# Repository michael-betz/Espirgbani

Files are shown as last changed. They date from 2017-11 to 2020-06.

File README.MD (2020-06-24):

# ESP Pinball RGB Animation clock

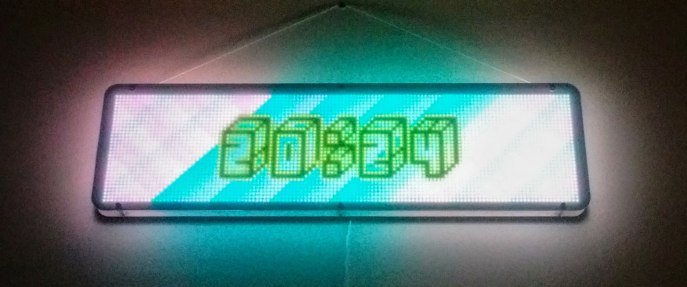
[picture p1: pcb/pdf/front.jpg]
clock


A LED-matrix clock, based on ESP32 and sprite_tm's I2S DMA driver.

__Note:__ 
the firmware here is outdated and will be removed in the future. 

[Espirgbani_pio](https://github.com/yetifrisstlama/espirgbani_pio) is up to date, has more features, less bugs, higher frame-rate and is much easier to build.

[Project log](http://yetifrisstlama.blogspot.com/2018/02/the-esp32-pinball-rgb-matrix-animation.html).

# PCB
Fits inside one of the 64x32 panels.

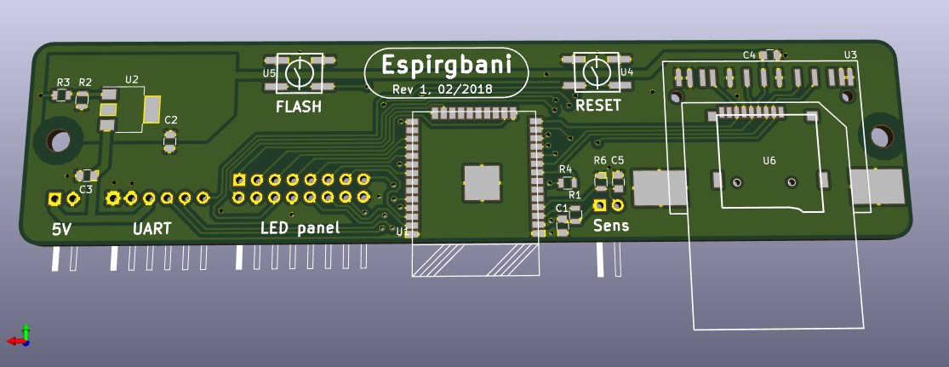
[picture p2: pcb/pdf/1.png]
back


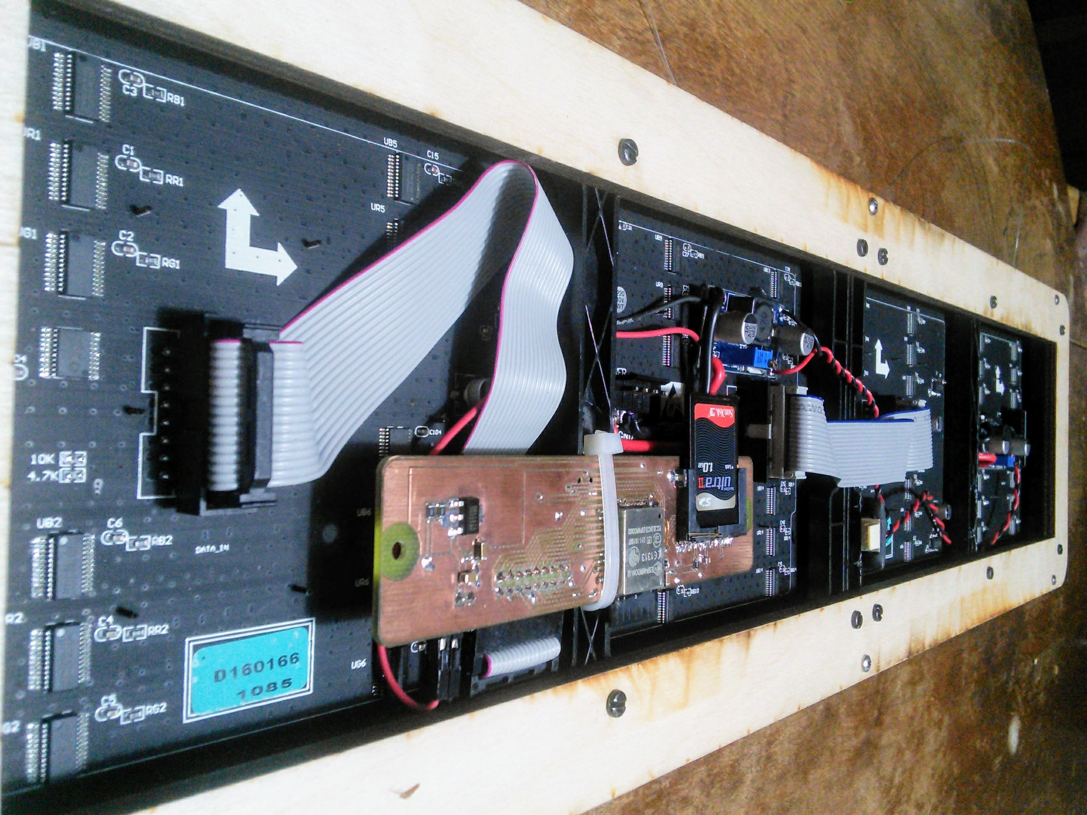
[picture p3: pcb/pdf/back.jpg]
wiring


### Revisions
Changes included in Rev 1
  * Change programming port from custom pogo-pins to a normal header
  * Add input for ambient light level sensor
  * Re-arrange the mounting holes
  * Add second footprint for a uSD card

# Building
Unfortunately the projects which I based this software on are either completely obsolete or they moved on a lot. Building still works (as of April 2020) but only when using exactly the versions and git commits as specified below.

install [version 5.2.0 of `xtensa-esp32-elf` toolchain](https://dl.espressif.com/dl/xtensa-esp32-elf-linux64-1.22.0-80-g6c4433a-5.2.0.tar.gz) and put it in your `PATH`.

```bash
$ xtensa-esp32-elf-gcc --version
xtensa-esp32-elf-gcc (crosstool-NG crosstool-ng-1.22.0-80-g6c4433a) 5.2.0
Copyright (C) 2015 Free Software Foundation, Inc.
This is free software; see the source for copying conditions.  There is NO
warranty; not even for MERCHANTABILITY or FITNESS FOR A PARTICULAR PURPOSE.
```

install the esp-idf library.
```bash
git clone https://github.com/espressif/esp-idf.git
cd esp-idf
git checkout b173cf28174b17f7df96c298f83c16a00d22e312
git submodule init
git submodule update
cd components
git clone --recurse-submodules git@github.com:yetifrisstlama/libesphttpd.git
export IDF_PATH=<insert_path>/esp-idf
```

Clone Espirgbani, build and flash it ...

```bash
git clone git@github.com:yetifrisstlama/Espirgbani.git
cd Espirgbani/src
make
make flash     # program esp32 over serial port, hold the FLASH button!
make web-flash # program esp32 over wifi, set hostname in Makefile
```

## fast-seek
For a smoother animation playback, the fast-seek option needs to be enabled in
the fatfs library. Use the provided .patch file ...
```bash
cd esp-idf
patch -p1 -i ../Espirgbani/src/0001-Enable-FASTSEEK-option-in-FatFs.patch
```

# SD card instructions
Format as FAT32, then copy the following files:
  * `./settings.json`
  * `./runDmd.img`
  * `./fnt/{d}.fnt`
  * `./fnt/{d}_0.bmp`

## example `settings.json`
```json
{
    "panel": {
        "test_pattern": false,
        "tp_brightness":  10,
        "is_clk_inverted": true,
        "column_swap": false,
        "latch_offset": 0,
        "extra_blank": 1,
        "clkm_div_num": 4
    },
    "power": {
        "hi": {
            "h": 9,
            "m": 0,
            "p": 50,
            "pingIp": "192.168.1.208"
        },
        "lo": {
            "h": 22,
            "m": 45,
            "p": 1
        }
    },
    "delays": {
        "font":  60,
        "color": 10,
        "ani":   15,
        "ping":  60
    },
    "log_level": "W",
    "timezone": "PST8PDT,M3.2.0,M11.1.0",
    "hostname": "espirgbani",
    "wifis": {
        "<wifi-ssid>": {
            "pw": "<wifi-password>"
        }
    }
}
```
### `panel` section
Not all LED panels are the same. Here the timing parameters of the I2S panel driver can be configured.

  * `test_pattern`: if true, enters a LED panel test mode instead of normal operation
  * `tp_brightness`: brightness of the test pattern, from 1 to 127. Current draw gets ridiculous for the higher values
  * `is_clk_inverted`: if `false`, data changes on the rising clock edge. If `true`, data is stable on the rising clock edge (most panels need `true`)
  * `column_swap`: if true, swap each pair of vertical columns
  * when `latch_offset = 0`: latch row-data with last pixel. For positive / negative numbers the latching happens n clock cycles earlier / later. Shifts the image horizontally
  * `extra_blank` adds N additional delay cycles after latching before enabling the LEDs to prevent ghosting artifacts from one row to another
  * `clkm_div_num` sets the I2S clock divider from 1 to 128. Set it too high and get flicker,  too low get ghost pixels. `4` (= 8 MHz pixel clock) is a good compromise for my panels

### `power` section
controls the display brightness depending on current time.

  * Switches to brightness `90` at `9:00`
  * But only if `192.168.1.208` responds to pings
  * Switches to brightness `1` at `22:45`

### `delays` section
controls delays between random animations, color and font changes.

  * Changes the clock font every 60 minutes
  * Changes color of the clock font every 10 minutes
  * Plays a new pinball animation every 15 seconds
  * tries to ping `pingIp` every 60 seconds

### `log_level`
is the logging level for the serial port and the web-console on startup. Can be one of the following letters: `E = ERROR`, `W = WARN`, `I = INFO`, `D = DEBUG`, `V = VERBOSE`

### `timezone`
is the local timezone in [TZ format](https://www.gnu.org/software/libc/manual/html_node/TZ-Variable.html). Look it up [here](https://github.com/nayarsystems/posix_tz_db/blob/master/zones.csv).

Note that once running and connected to the wifi, the settings.json file can be edited through the web interface.

## how to get `runDmd.img`
  * Find a run-dmd image file and write it to SD card according to their instructions (HDD Raw Copy Tool and Windows required)
  * In linux, dump the first few hundred megabytes of the SD card to a file:
  ```bash
  sudo dd if=/dev/sdb of=./runDmd.img bs=1M count=125
  ```

## how to get the font `.bmp` and `.fnt` files
  * Find some nice fonts which look good at small size and copy the `.ttf` files into the git tree at `./dev/fonts`
  * Use [bmFont](http://www.angelcode.com/products/bmfont/) (works well with wine in linux) to generate the bitmap fonts. Good settings are provided in `dev/clockFont.bmfc`
    * Width: 52, Height: 2000
    * 32 bit per pixel (A = one, R = glyph, G = outline, B = zero)
    * .png texture file
    * binary .fnt descriptor file
    * Size: 30 px, Outline thickness: 1 px
  * Use imagemagick to convert all image files to bmp format
  * Rename them to 0_0.bmp, 0.fnt;  1_0.bmp, 1.fnt, ...
  * Alternatively, run `./dev/generateFonts.sh` which should automate these steps

## Pre-built binaries (TLDR!)
Prebuilt firmware binaries for the ESP32 and the files for the (FAT32) SD card are [here](https://github.com/yetifrisstlama/Espirgbani/releases/tag/v1.0).

# TODO
  * rewrite .json settings

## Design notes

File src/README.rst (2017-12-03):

EXAMPLE TO USE I2S TO DRIVE A LED DISPLAY
=========================================

This is example code to drive one of the common 64x32-pixel RGB LED
screen. It illustrates the parallel output mode of the I2S peripheral.

See main/app_main.c for more information and how to hook up a display.

This is PRELIMINARY CODE and Espressif gives no support on it.

https://esp32.com/viewtopic.php?f=17&t=3188&sid=14a745f714c2d902012ac641bb31025d

Modified to 128x64 and with GLCD / webserver code by M. Betz

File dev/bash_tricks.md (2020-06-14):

# extract all zip files
```bash
for f in *zip; do unar $f; done
```

# move all .ttf files into ./fnt
```bash
shopt -s globstar
for f in **/*.ttf; do mv "$f" ./fnt; done
```

# rename to 00.ttf, 01.ttf, etc
```bash
i=0; for f in *.ttf; do mv "$f" "$(printf %02d.ttf $i)"; i=$((i+1)); done
```

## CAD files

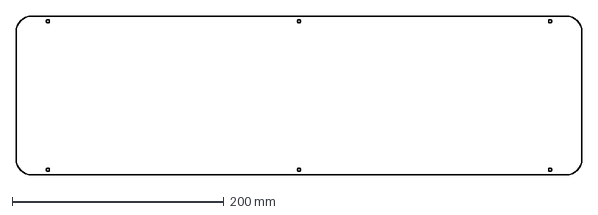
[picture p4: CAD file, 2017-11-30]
pcb/lasercut/frontAcryl.dxf
534.0 x 150.0 mm

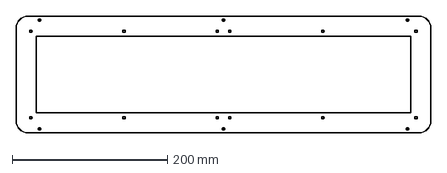
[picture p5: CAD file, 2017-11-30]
pcb/lasercut/backWood.dxf
534.0 x 150.0 mm

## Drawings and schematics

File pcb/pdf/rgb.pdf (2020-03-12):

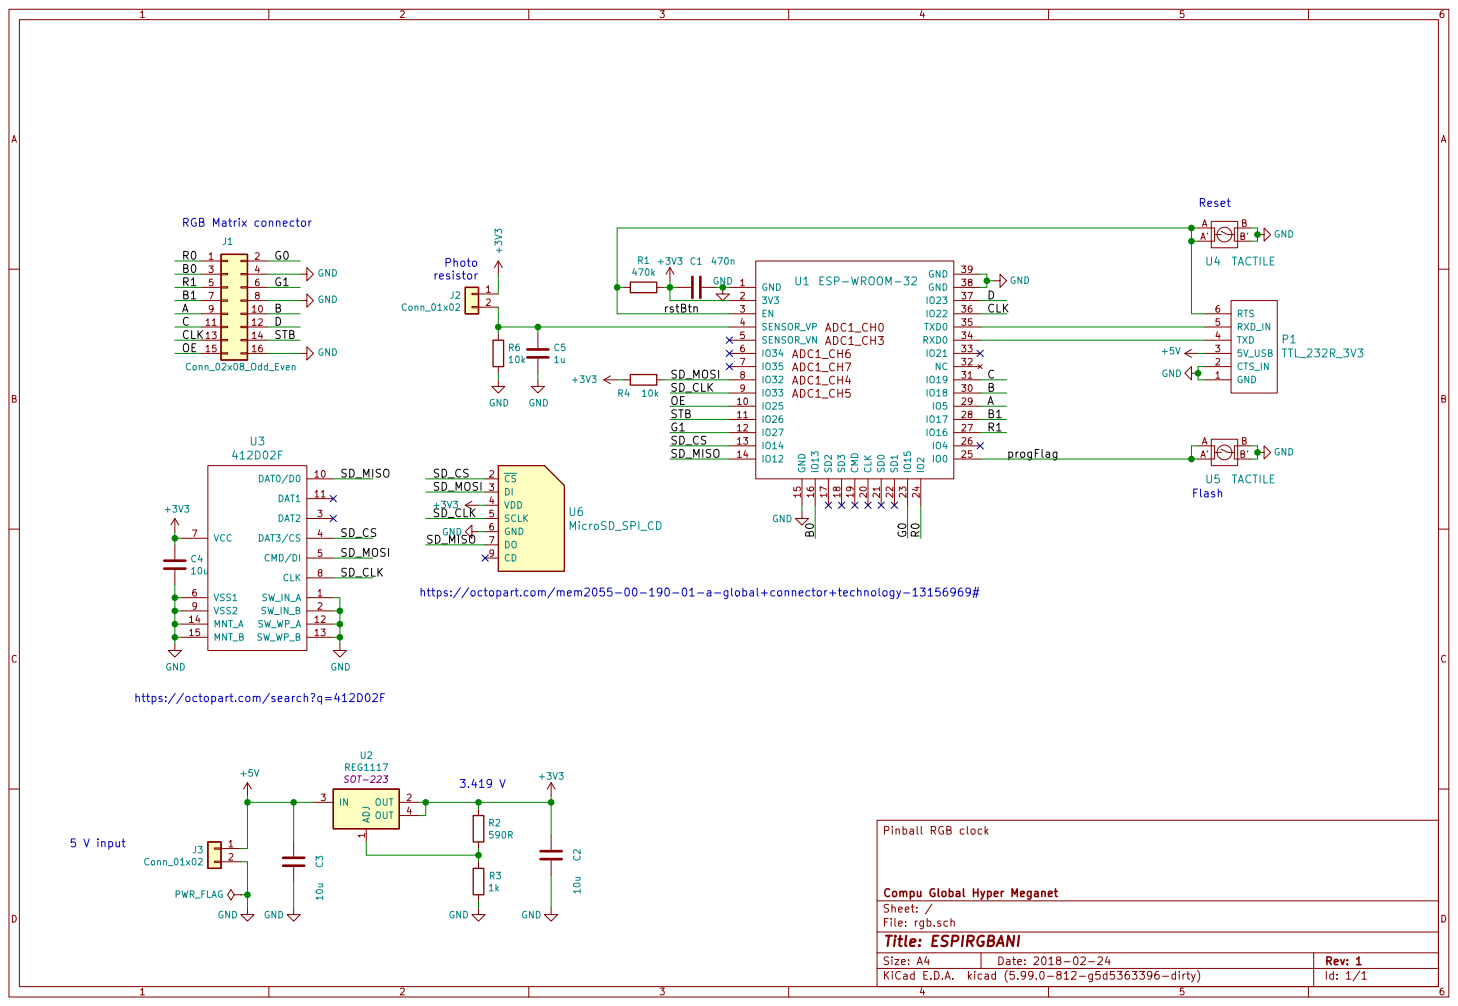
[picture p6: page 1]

https://octopart.com/mem2055-00-190-01-a-global+connector+technology-13156969# Photo

https://octopart.com/search?q=412D02F

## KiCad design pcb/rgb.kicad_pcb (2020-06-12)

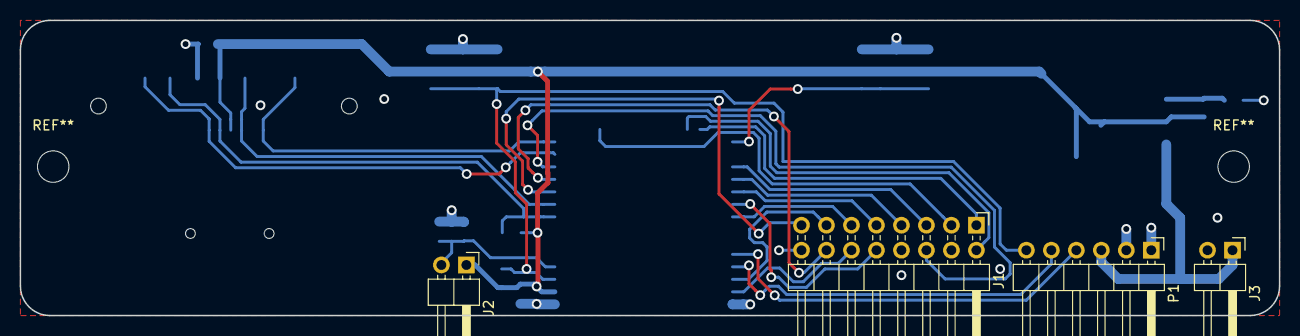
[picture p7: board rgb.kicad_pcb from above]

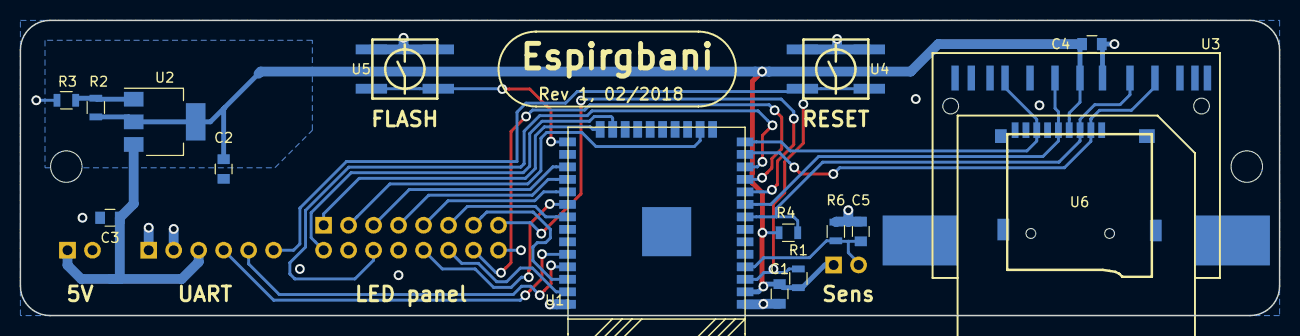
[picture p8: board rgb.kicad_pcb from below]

Board: 2 copper layers, 128.0 x 30.0 mm, 20 parts (16 on the bottom side), 26 nets.

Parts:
C1: 470n; C_0805
C2, C3, C4: 10u; C_0805
C5: 1u; C_0805
J1: Conn_02x08_Odd_Even; Pin_Header_Angled_2x08_Pitch2.54mm
J2, J3: Conn_01x02; Pin_Header_Angled_1x02_Pitch2.54mm
P1: TTL_232R_3V3; Pin_Header_Angled_1x06_Pitch2.54mm
R1: 470k; R_0805
R2: 590R; R_0805
R3: 1k; R_0805
R4, R6: 10k; R_0805
U1: ESP-WROOM-32
U2: REG1117; SOT-223
U3: 412D02F; RPIA_SD_CARD
U4, U5: TACTILE; EVQQ2
U6: MicroSD_SPI_CD; GCT-MEM2055-00-190-01-A

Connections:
+3V3: C1.2, C2.2, C4.1, J2.1, R1.1, R2.1, R4.2, U1.2, U2.2, U2.4, U3.7, U6.4
+5V: C3.2, J3.1, P1.3, U2.3
/A: J1.9, U1.29
/B: J1.10, U1.30
/B0: J1.3, U1.16
/B1: J1.7, U1.28
/C: J1.11, U1.31
/CLK: J1.13, U1.36
/D: J1.12, U1.37
/G0: J1.2, U1.23
/G1: J1.6, U1.12
/OE: J1.15, U1.10
/R0: J1.1, U1.24
/R1: J1.5, U1.27
/SD_CLK: U1.9, U3.8, U6.5
/SD_CS: U1.13, U3.4, U6.2
/SD_MISO: U1.14, U3.10, U6.7
/SD_MOSI: R4.1, U1.8, U3.5, U6.3
/STB: J1.14, U1.11
/progFlag: U1.25, U5.A, U5.A'
/rstBtn: P1.6, R1.2, U1.3, U4.A, U4.A'
GND: C1.1, C2.1, C3.1, C4.2, C5.2, J1.4, J1.8, J1.16, J3.2, P1.1, P1.2, R3.2, R6.2, U1.1, U1.15, U1.38, U1.39, U3.1, U3.2, U3.6, U3.9, U3.12, U3.13, U3.14, U3.15, U4.B, U4.B', U5.B, U5.B', U6.6
unnamed: C5.1, J2.2, R6.1, U1.4
unnamed: P1.4, U1.34
unnamed: P1.5, U1.35
unnamed: R2.2, R3.1, U2.1

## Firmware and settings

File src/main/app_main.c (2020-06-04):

// Copyright 2017 Espressif Systems (Shanghai) PTE LTD
//
// Licensed under the Apache License, Version 2.0 (the "License");
// you may not use this file except in compliance with the License.
// You may obtain a copy of the License at
//
//     http://www.apache.org/licenses/LICENSE-2.0
//
// Unless required by applicable law or agreed to in writing, software
// distributed under the License is distributed on an "AS IS" BASIS,
// WITHOUT WARRANTIES OR CONDITIONS OF ANY KIND, either express or implied.
// See the License for the specific language governing permissions and
// limitations under the License.

#include <string.h>
#include <stdio.h>
#include <stdlib.h>
#include <math.h>
#include <time.h>
#include "driver/gpio.h"
#include "esp_log.h"
#include "wifi_startup.h"
#include "web_console.h"
#include "rgb_led_panel.h"
#include "sdcard.h"
#include "animations.h"
#include "frame_buffer.h"
#include "bmp.h"
#include "font.h"
#include "shaders.h"
#include "fast_hsv2rgb.h"
#include "app_main.h"
#include "json_settings.h"

static const char *T = "MAIN_APP";

int g_maxFnt = 0;
int g_fontNumberRequest = 0;

void seekToFrame(FILE *f, int byteOffset, int frameOffset) {
    byteOffset += DISPLAY_WIDTH * DISPLAY_HEIGHT * frameOffset / 2;
    fseek(f, byteOffset, SEEK_SET);
}

void playAni(FILE *f, headerEntry_t *h) {
    uint8_t r,g,b;
    fast_hsv2rgb_32bit(RAND_AB(0,HSV_HUE_MAX), HSV_SAT_MAX, HSV_VAL_MAX, &r, &g, &b);
    for(int i=0; i<h->nFrameEntries; i++) {
        frameHeaderEntry_t fh = h->frameHeader[i];
        if(fh.frameId == 0) {
            startDrawing(2);
            setAll(2, 0xFF000000);
        } else {
            seekToFrame(f, h->byteOffset+HEADER_SIZE, fh.frameId-1);
            startDrawing(2);
            setFromFile(f, 2, SRGBA(r,g,b,0xFF));
        }
        doneDrawing(2);
        // updateFrame();
        vTaskDelay(fh.frameDur / portTICK_PERIOD_MS);
    }
}

void manageBrightness(struct tm *timeinfo) {
    static int nBadPings = 0;
    cJSON *jPow = jGet(getSettings(), "power");
    cJSON *jDel = jGet(getSettings(), "delays");
    cJSON *jHi  = jGet(jPow, "hi");
    cJSON *jLo  = jGet(jPow, "lo");
    const char *pingIpStr;
    uint32_t pingRespTime;
    ip4_addr_t ip;
    pingIpStr = jGetS(jHi, "pingIp", "0.0.0.0");
    ip4addr_aton(pingIpStr, &ip);
    int maxBadPings = jGetI(jDel, "ping", 1);
    if (maxBadPings <= 0) maxBadPings = 1;
    int iHi = jGetI(jHi, "m", 0) + jGetI(jHi, "h", 9) * 60;
    int iLo = jGetI(jLo, "m", 45) + jGetI(jLo,"h", 22) * 60;
    int iCur = timeinfo->tm_min + timeinfo->tm_hour * 60;
    if (iCur >= iHi && iCur < iLo) {
        // Daylite mode
        brightNessState = BR_DAY;
        if (ip.addr > 0 && ip.addr < 0xFFFFFFFF) {
            if ((pingRespTime = isPingOk(&ip, 3000))) {
                nBadPings = 0;
                ESP_LOGD(T,"Ping response from %s in %d ms", ip4addr_ntoa(&ip), pingRespTime);
            } else {
                nBadPings++;
                ESP_LOGW(T,"Ping timeout %d on %s", nBadPings, ip4addr_ntoa(&ip));
            }
            if (nBadPings >= maxBadPings) {
                g_rgbLedBrightness = jGetI(jLo, "p", 1);
            } else {
                g_rgbLedBrightness = jGetI(jHi, "p", 20);
            }
        } else {
            g_rgbLedBrightness = jGetI(jHi, "p", 20);
        }
    } else {
        // Night mode
        brightNessState = BR_NIGHT;
        g_rgbLedBrightness = jGetI(jLo, "p", 1);
    }
}

void aniClockTask(void *pvParameters) {
    // takes care of things which need to happen
    // every minute (like redrawing the clock)
    time_t now = 0;
    struct tm timeinfo;
    timeinfo.tm_min =  0;
    timeinfo.tm_hour= 18;
    char strftime_buf[64];

    unsigned col = rand();
    unsigned ticks_font=0, ticks_color=0;  // for counting ticks [min]
    cJSON *jDelay = jGet(getSettings(), "delays");
    TickType_t xLastWakeTime;
    xLastWakeTime = xTaskGetTickCount();

    ESP_LOGI(T,"aniClockTask started");

    // count font files and choose a random one
    g_maxFnt = cntFntFiles("/sd/fnt") - 1;
    if (g_maxFnt < 0) {
        ESP_LOGE(T, "no fonts found on SD card");
        g_fontNumberRequest = -1;
    } else {
        ESP_LOGI(T, "max. font file: /sd/fnt/%d.fnt", g_maxFnt);
        g_fontNumberRequest = RAND_AB(0, g_maxFnt);
    }

    while(1) {
        ESP_LOGD(T, " ticks_font: %u, max: %d", ticks_font, jGetI(jDelay, "font", 60));
        if (g_maxFnt > 0 && ticks_font > jGetI(jDelay, "font", 60)) {
            // every delays.font minutes
            g_fontNumberRequest = RAND_AB(0, g_maxFnt);
            ticks_font = 0;
        }
        if (ticks_color > jGetI(jDelay, "color", 10)) {
            col = 0xFF000000 | rand();
            ticks_color = 0;
        }
        // every minute
        if(g_maxFnt > 0 && g_fontNumberRequest >= 0 && g_fontNumberRequest <= g_maxFnt) {
            sprintf(strftime_buf, "/sd/fnt/%d", g_fontNumberRequest);
            initFont(strftime_buf);
            g_fontNumberRequest = -1;
        }
        // Redraw the clock
        time(&now);
        localtime_r(&now, &timeinfo);
        strftime(strftime_buf, sizeof(strftime_buf), "%H:%M", &timeinfo);
        drawStrCentered(strftime_buf, 1, col, 0xFF000000);
        manageBrightness(&timeinfo);
        ticks_font++;
        ticks_color++;

        // wait for the next minute
        vTaskDelayUntil(&xLastWakeTime, 1000 * 60 / portTICK_PERIOD_MS);
    }
    vTaskDelete(NULL);
}

static void IRAM_ATTR gpio_isr_handler(void* arg) {
    wifiState = WIFI_START_HOTSPOT_MODE;
}

void tp_stripes(unsigned width, unsigned offset, bool isY)
{
    for (unsigned y=0; y<DISPLAY_HEIGHT; y++) {
        for (unsigned x=0; x<DISPLAY_WIDTH; x++) {
            unsigned var = isY ? x : y;
            unsigned col = (var + offset) % width == 0 ? 0xFFFFFFFF : 0xFF000000;
            setPixel(2, x, y, col);
        }
    }
    updateFrame();
}

void tp_stripes_sequence(bool isY)
{
    for (unsigned i=0; i<8; i++) {
        ESP_LOGI(T, "stripes %d / 8", i + 1);
        tp_stripes(8, i, isY);
        vTaskDelay(1000 / portTICK_PERIOD_MS);
    }
    for (unsigned i=0; i<4; i++) {
        ESP_LOGI(T, "stripes %d / 2", (i % 2) + 1);
        tp_stripes(2, i % 2, isY);
        vTaskDelay(1000 / portTICK_PERIOD_MS);
    }
}

void app_main() {
    //------------------------------
    // Enable RAM log file
    //------------------------------
    esp_log_level_set("*", ESP_LOG_INFO);
    esp_log_set_vprintf(wsDebugPrintf);
    srand(esp_random());

    //------------------------------
    // Init filesystems
    //------------------------------
    initSpiffs();
    initSd();
    setLogLevel(*jGetS(getSettings(), "log_level", "W"));

    //------------------------------
    // Init rgb tiles
    //------------------------------
    // with .json settings, display HelloWrld
    g_rgbLedBrightness = 10;
    init_rgb();
    if (!initFont("/sd/fnt/2")) {
        // TODO: try to fallback on font in spiffs
        initFont("/spiffs/fnt");
    }
    setAll(2, 0x00000000);
    drawStrCentered("HelloWrld", 1, 0xFF222222, 0xFF000000);
    updateFrame();

    //------------------------------
    // Pushing flash button triggers access point mode
    //------------------------------
    gpio_config_t io_conf;
    //interrupt of falling edge
    io_conf.intr_type = GPIO_PIN_INTR_NEGEDGE;
    //bit mask of the pins, use GPIO0 here
    io_conf.pin_bit_mask = (1<<0);
    //set as input mode
    io_conf.mode = GPIO_MODE_INPUT;
    //enable pull-up mode
    io_conf.pull_up_en = 1;
    gpio_config(&io_conf);
    //install gpio isr service
    gpio_install_isr_service(0);
    //hook isr handler for specific gpio pin
    gpio_isr_handler_add(0, gpio_isr_handler, 0);

    //------------------------------
    // Startup wifi & webserver
    //------------------------------
    ESP_LOGI(T,"Starting network infrastructure ...");
    wifi_conn_init();

    //------------------------------
    // display test-pattern
    //------------------------------
    // only if enabled in json
    cJSON *jPanel = jGet(getSettings(), "panel");
    if (jGetB(jPanel, "test_pattern", false)) {
        g_rgbLedBrightness = jGetI(jPanel, "tp_brightness", 10);
        if (g_rgbLedBrightness < 1) g_rgbLedBrightness = 1;
        while(1) {
            ESP_LOGI(T, "Test-pattern mode!!!");
            setAll(0, 0xFF000000);
            setAll(1, 0xFF000000);
            setAll(2, 0xFF000000);
            updateFrame();

            ESP_LOGI(T, "Diagonal");
            for (unsigned y=0; y<DISPLAY_HEIGHT; y++)
                for (unsigned x=0; x<DISPLAY_WIDTH; x++)
                    setPixel(2, x, y, (x - y) % DISPLAY_HEIGHT == 0 ? 0xFFFFFFFF : 0xFF000000);
            updateFrame();
            vTaskDelay(5000 / portTICK_PERIOD_MS);

            ESP_LOGI(T, "Vertical stripes ...");
            tp_stripes_sequence(true);

            ESP_LOGI(T, "Horizontal stripes ...");
            tp_stripes_sequence(false);

            ESP_LOGI(T, "All red");
            setAll(2, 0xFF0000FF);
            updateFrame();
            vTaskDelay(1000 / portTICK_PERIOD_MS);

            ESP_LOGI(T, "All green");
            setAll(2, 0xFF00FF00);
            updateFrame();
            vTaskDelay(1000 / portTICK_PERIOD_MS);

            ESP_LOGI(T, "All blue");
            setAll(2, 0xFFFF0000);
            updateFrame();
            vTaskDelay(1000 / portTICK_PERIOD_MS);
        }
    }

    xEventGroupWaitBits(wifi_event_group, CONNECTED_BIT, 0, 0, 20000 / portTICK_PERIOD_MS);
    updateFrame();
    vTaskDelay(3000 / portTICK_PERIOD_MS);

    //------------------------------
    // Set the clock / print time
    //------------------------------
    // Set timezone to Eastern Standard Time and print local time
    const char *tz_str = jGetS(getSettings(), "timezone", "PST8PDT");
    ESP_LOGI(T,"Setting timezone to TZ = %s", tz_str);
    setenv("TZ", tz_str, 1);
    tzset();
    time_t now = 0;
    struct tm timeinfo = { 0 };
    char strftime_buf[64];
    time(&now);
    localtime_r(&now, &timeinfo);
    strftime(strftime_buf, sizeof(strftime_buf), "%c", &timeinfo);
    ESP_LOGI(T, "Local Time: %s (%ld)", strftime_buf, time(NULL));
    srand(time(NULL));

    //------------------------------
    // Startup animated background layer
    //------------------------------
    xTaskCreate(&aniBackgroundTask, "aniBackground", 4096, NULL, 0, NULL);

    //------------------------------
    // Startup clock layer
    //------------------------------
    xTaskCreate(&aniClockTask, "aniClock", 4096, NULL, 0, NULL);

    //------------------------------
    // Read animation file from SD
    //------------------------------
    FILE *f = fopen(ANIMATION_FILE, "r");
    if (!f) {
        ESP_LOGE(T, "fopen(%s, rb) failed: %s", ANIMATION_FILE, strerror(errno));
        ESP_LOGE(T, "Will not show animations!");
        goto exit_main_task;
    }

    fileHeader_t fh;
    getFileHeader(f, &fh);
    printf("Build: %s, Found %d animations\n\n", fh.buildStr, fh.nAnimations);
    fseek(f, HEADER_OFFS, SEEK_SET);
    headerEntry_t myHeader;

    int aniId;
    cJSON *jDelay = jGet(getSettings(), "delays");

    while (1) {
        vTaskDelay(jGetI(jDelay, "ani", 15) * 1000 / portTICK_PERIOD_MS);

        aniId = RAND_AB(0, fh.nAnimations-1);
        readHeaderEntry(f, &myHeader, aniId);
        ESP_LOGD(T, "%s", myHeader.name);
        ESP_LOGD(T, "--------------------------------");
        ESP_LOGD(T, "animationId:       0x%04X", myHeader.animationId);
        ESP_LOGD(T, "nStoredFrames:         %d", myHeader.nStoredFrames);
        ESP_LOGD(T, "byteOffset:    0x%08X", myHeader.byteOffset);
        ESP_LOGD(T, "nFrameEntries:         %d", myHeader.nFrameEntries);
        ESP_LOGD(T, "width:               0x%02X", myHeader.width);
        ESP_LOGD(T, "height:              0x%02X", myHeader.height);
        ESP_LOGD(T, "unknowns:            0x%02X", myHeader.unknown0);
        ESP_LOG_BUFFER_HEX_LEVEL(T, myHeader.unknown1, sizeof(myHeader.unknown1), ESP_LOG_DEBUG);
        ESP_LOGD(T, "frametimes:");
        ESP_LOG_BUFFER_HEX_LEVEL(T, myHeader.frameHeader, myHeader.nFrameEntries*2, ESP_LOG_DEBUG);
        playAni(f, &myHeader);
        free(myHeader.frameHeader);
        myHeader.frameHeader = NULL;

        // Keep a single frame displayed for a bit
        if (myHeader.nStoredFrames <= 3 || myHeader.nFrameEntries <= 3)
            vTaskDelay(3000 / portTICK_PERIOD_MS);

        // Fade out the frame
        uint32_t nTouched = 1;
        while (nTouched) {
            startDrawing(2);
            nTouched = fadeOut(2, 10);
            doneDrawing(2);
            vTaskDelay(20 / portTICK_PERIOD_MS);
        }
        startDrawing(2);
        setAll(2, 0x00000000);    //Make layer fully transparent
        doneDrawing(2);
    }
    fclose(f);

exit_main_task:
    vTaskDelete(NULL);
}

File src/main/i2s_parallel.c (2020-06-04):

// Copyright 2017 Espressif Systems (Shanghai) PTE LTD
//
// Licensed under the Apache License, Version 2.0 (the "License");
// you may not use this file except in compliance with the License.
// You may obtain a copy of the License at
//
//     http://www.apache.org/licenses/LICENSE-2.0
//
// Unless required by applicable law or agreed to in writing, software
// distributed under the License is distributed on an "AS IS" BASIS,
// WITHOUT WARRANTIES OR CONDITIONS OF ANY KIND, either express or implied.
// See the License for the specific language governing permissions and
// limitations under the License.

#include <stdio.h>
#include <stdint.h>
#include <stddef.h>
#include <string.h>

#include "freertos/FreeRTOS.h"
#include "freertos/task.h"
#include "freertos/semphr.h"
#include "freertos/queue.h"

#include "soc/i2s_struct.h"
#include "soc/i2s_reg.h"
#include "driver/periph_ctrl.h"
#include "driver/gpio.h"
#include "soc/io_mux_reg.h"
#include "rom/lldesc.h"
#include "esp_heap_caps.h"
#include "i2s_parallel.h"

typedef struct {
    volatile lldesc_t *dmadesc_a, *dmadesc_b;
    int desccount_a, desccount_b;
} i2s_parallel_state_t;

static i2s_parallel_state_t *i2s_state[2]={NULL, NULL};

#define DMA_MAX (4096-4)

//Calculate the amount of dma descs needed for a buffer desc
static int calc_needed_dma_descs_for(i2s_parallel_buffer_desc_t *desc) {
    int ret=0;
    for (int i=0; desc[i].memory!=NULL; i++) {
        ret+=(desc[i].size+DMA_MAX-1)/DMA_MAX;
    }
    return ret;
}

static void fill_dma_desc(volatile lldesc_t *dmadesc, i2s_parallel_buffer_desc_t *bufdesc) {
    int n=0;
    for (int i=0; bufdesc[i].memory!=NULL; i++) {
        int len=bufdesc[i].size;
        uint8_t *data=(uint8_t*)bufdesc[i].memory;
        while(len) {
            int dmalen=len;
            if (dmalen>DMA_MAX) dmalen=DMA_MAX;
            dmadesc[n].size=dmalen;
            dmadesc[n].length=dmalen;
            dmadesc[n].buf=data;
            dmadesc[n].eof=0;
            dmadesc[n].sosf=0;
            dmadesc[n].owner=1;
            dmadesc[n].qe.stqe_next=(lldesc_t*)&dmadesc[n+1];
            dmadesc[n].offset=0;
            len-=dmalen;
            data+=dmalen;
            n++;
        }
    }
    //Loop last back to first
    dmadesc[n-1].qe.stqe_next=(lldesc_t*)&dmadesc[0];
    printf("fill_dma_desc: filled %d descriptors\n", n);
}

static void gpio_setup_out(int gpio, int sig, bool isInverted) {
    if (gpio==-1) return;
    PIN_FUNC_SELECT(GPIO_PIN_MUX_REG[gpio], PIN_FUNC_GPIO);
    gpio_set_direction(gpio, GPIO_MODE_DEF_OUTPUT);
    gpio_matrix_out(gpio, sig, isInverted, false);
}


static void dma_reset(i2s_dev_t *dev) {
    dev->lc_conf.in_rst=1; dev->lc_conf.in_rst=0;
    dev->lc_conf.out_rst=1; dev->lc_conf.out_rst=0;
}

static void fifo_reset(i2s_dev_t *dev) {
    dev->conf.rx_fifo_reset=1; dev->conf.rx_fifo_reset=0;
    dev->conf.tx_fifo_reset=1; dev->conf.tx_fifo_reset=0;
}

static int i2snum(i2s_dev_t *dev) {
    return (dev==&I2S0)?0:1;
}

void i2s_parallel_setup(i2s_dev_t *dev, const i2s_parallel_config_t *cfg) {
    //Figure out which signal numbers to use for routing
    printf("Setting up parallel I2S bus at I2S%d\n", i2snum(dev));
    int sig_data_base, sig_clk;
    if (dev==&I2S0) {
        sig_data_base=I2S0O_DATA_OUT0_IDX;
        sig_clk=I2S0O_WS_OUT_IDX;
    } else {
        if (cfg->bits==I2S_PARALLEL_BITS_32) {
            sig_data_base=I2S1O_DATA_OUT0_IDX;
        } else {
            //Because of... reasons... the 16-bit values for i2s1 appear on d8...d23
            sig_data_base=I2S1O_DATA_OUT8_IDX;
        }
        sig_clk=I2S1O_WS_OUT_IDX;
    }

    //Route the signals
    for (int x=0; x<cfg->bits; x++) {
        gpio_setup_out(cfg->gpio_bus[x], sig_data_base+x, false);
    }
    //ToDo: Clk/WS may need inversion?
    gpio_setup_out(cfg->gpio_clk, sig_clk, cfg->is_clk_inverted);

    //Power on dev
    if (dev==&I2S0) {
        periph_module_enable(PERIPH_I2S0_MODULE);
    } else {
        periph_module_enable(PERIPH_I2S1_MODULE);
    }
    //Initialize I2S dev
    dev->conf.rx_reset=1; dev->conf.rx_reset=0;
    dev->conf.tx_reset=1; dev->conf.tx_reset=0;
    dma_reset(dev);
    fifo_reset(dev);

    //Enable LCD mode
    dev->conf2.val=0;
    dev->conf2.lcd_en=1;

    dev->sample_rate_conf.val=0;
    dev->sample_rate_conf.rx_bits_mod=cfg->bits;
    dev->sample_rate_conf.tx_bits_mod=cfg->bits;
    dev->sample_rate_conf.rx_bck_div_num=4; //ToDo: Unsure about what this does...
    dev->sample_rate_conf.tx_bck_div_num=4;

    dev->clkm_conf.val=0;
    dev->clkm_conf.clka_en=0;
    dev->clkm_conf.clkm_div_a=1;
    dev->clkm_conf.clkm_div_b=1;
    //We ignore the possibility for fractional division here.
    dev->clkm_conf.clkm_div_num=cfg->clk_div;


    dev->fifo_conf.val=0;
    dev->fifo_conf.rx_fifo_mod_force_en=1;
    dev->fifo_conf.tx_fifo_mod_force_en=1;
    dev->fifo_conf.rx_data_num=32; //Thresholds.
    dev->fifo_conf.tx_data_num=32;
    dev->fifo_conf.dscr_en=1;

    dev->conf1.val=0;
    dev->conf1.tx_stop_en=0;
    dev->conf1.tx_pcm_bypass=1;

    dev->conf_chan.val=0;

    // flicker hack, initialize in mode 0 instead of mode 1
    // this puts output words in natural order,
    // instead of swapping them in pairs, like mode 1 does
    // also doubles the frequency
    I2S1.fifo_conf.tx_fifo_mod = 0;  // TX FIFO mode0, 16 bit dual channel data
    I2S1.conf_chan.tx_chan_mod = 0;  // dual channel mode
    I2S1.conf2.lcd_tx_wrx2_en = 1;   // if this is 0 in mode 0 output data in DDR mode!

    //Invert ws to be active-low... ToDo: make this configurable
    // ... this doesn't invert anything :p
    // but inversion can be done through the GPIO matrix :)
    dev->conf.tx_right_first=1;
    dev->conf.rx_right_first=1;

    dev->timing.val=0;

    //Allocate DMA descriptors
    i2s_state[i2snum(dev)]=malloc(sizeof(i2s_parallel_state_t));
    i2s_parallel_state_t *st=i2s_state[i2snum(dev)];
    st->desccount_a=calc_needed_dma_descs_for(cfg->bufa);
    st->desccount_b=calc_needed_dma_descs_for(cfg->bufb);
    st->dmadesc_a=heap_caps_malloc(st->desccount_a*sizeof(lldesc_t), MALLOC_CAP_DMA);
    st->dmadesc_b=heap_caps_malloc(st->desccount_b*sizeof(lldesc_t), MALLOC_CAP_DMA);

    //and fill them
    fill_dma_desc(st->dmadesc_a, cfg->bufa);
    fill_dma_desc(st->dmadesc_b, cfg->bufb);

    //Reset FIFO/DMA -> needed? Doesn't dma_reset/fifo_reset do this?
    dev->lc_conf.in_rst=1; dev->lc_conf.out_rst=1; dev->lc_conf.ahbm_rst=1; dev->lc_conf.ahbm_fifo_rst=1;
    dev->lc_conf.in_rst=0; dev->lc_conf.out_rst=0; dev->lc_conf.ahbm_rst=0; dev->lc_conf.ahbm_fifo_rst=0;
    dev->conf.tx_reset=1; dev->conf.tx_fifo_reset=1; dev->conf.rx_fifo_reset=1;
    dev->conf.tx_reset=0; dev->conf.tx_fifo_reset=0; dev->conf.rx_fifo_reset=0;
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

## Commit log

2017-12-01 Minimum example to show 1 (sub)frame for debugging
    [rgb.sch]
2017-12-03 First working version. MAtrix flickers when i2s clock si changed for bitplanes=7
    [partitions.csv]
2017-12-04 SD card is online and integrated into webserver
    [rgb.sch]
2017-12-04 Hmm sd card write bug?
    [cgi.c]
2018-01-29 Real premultiplied alpha support. drawing over conten in framebuffer now possible. font outline works now. alternative background pattern
2018-02-02 Added pics
    [backWood.dxf, frontAcryl.dxf]
2018-02-25 PCB REV1
    [rgb.kicad_pcb, rgb.sch]
2018-02-25 PCB rev1 mostly finished but untested
    [rgb.kicad_pcb]
2018-03-28 final pcb with second sd card slot and kicad 5
    [rgb.kicad_pcb, rgb.sch]
2018-04-21 Cosmetic improvements.
    [rgb.kicad_pcb]
2018-05-06 align fonts better, make delays configurabel
    [partitions.csv]
2018-05-11 Fix compiler warning by adding const char
    [app_main.c]
2018-05-11 Flash button = Hotspot mode, print status on leds
2018-08-04 Make number of bad pings configurable
    [partitions.csv]
2018-12-17 update PCB pictures
2019-01-15 Tried to fix startuptrouble
    [app_main.c, rgb_led_panel.c]
2020-03-12 pcb: fix value of V-REG, Add info about SD card sockets
    [rgb.kicad_pcb, rgb.sch]
2020-04-17 remove redundant .dxf files
    [laser_cut_back.dxf, laser_cut_front.dxf]
2020-06-01 fix 1 pixel x-offset
    [rgb_led_panel.c]
2020-06-04 make panel settings configurablei
    also invert clk signal
    [app_main.c, i2s_parallel.c, rgb_led_panel.c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]
2020-06-04 improve .json configuration
    * rgb panel driver can now be parametrized
    * this includes polarity of the clock signal, which was wrong before!
    * add test-pattern mode
    * make file handling much more robust. Starts up without SD card.
    [app_main.c, cgi.c]
2020-06-12 pcb: clean up project. Make kicad 5.1.x compatible
    [rgb.kicad_pcb, rgb.sch]
2020-06-12 pcb: re-save without copper zones
    [rgb.kicad_pcb]
